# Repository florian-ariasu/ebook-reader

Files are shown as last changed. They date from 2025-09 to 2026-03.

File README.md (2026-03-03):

# OpenBook E-Reader

A portable, open-source e-book reader built around the **ESP32-C6** microcontroller, featuring an energy-efficient E-Paper display, microSD storage, environmental sensing, and a comprehensive power management system.

---

## System Architecture

### Block Diagram

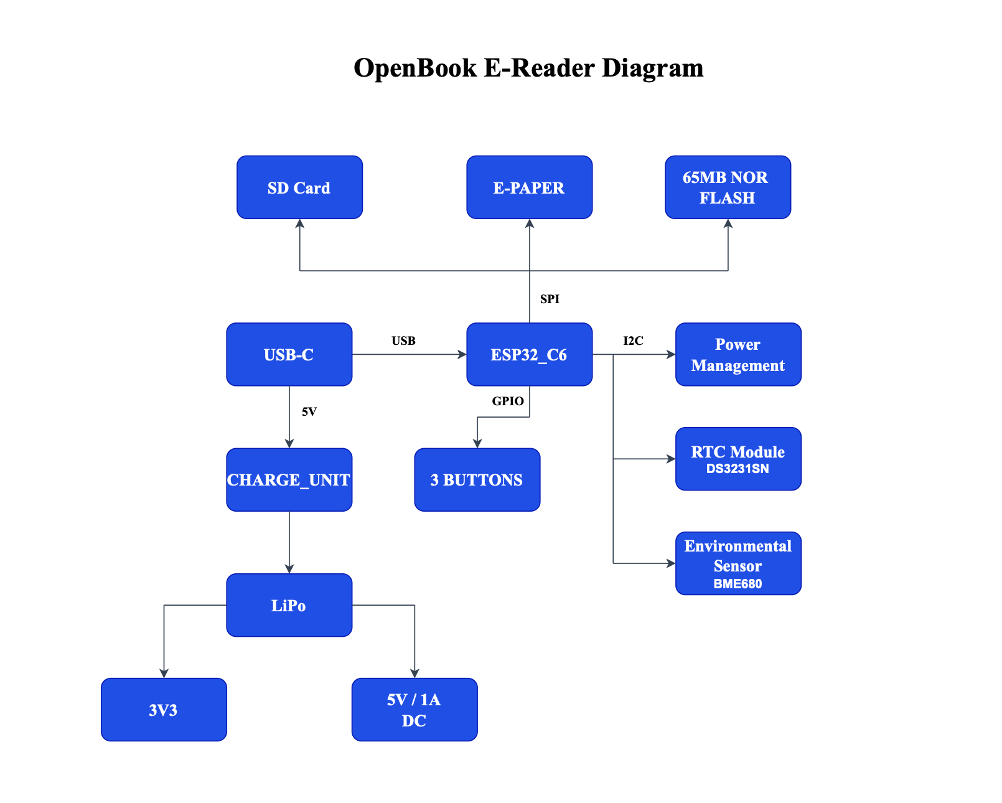
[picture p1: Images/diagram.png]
Block Diagram


The architecture focuses on a high-efficiency 3.3V power rail and shared communication buses (SPI/I2C):

- **ESP32-C6** – Main MCU managing UI, file systems, and wireless connectivity.
- **E-Paper Display** – 1.5" (200x200px) ultra-low-power screen.
- **Power Management** – Includes the **XC6220** 1A LDO for 3.3V regulation and **MCP73831** for Li-Po charging.
- **Battery Monitoring** – **MAX17048G+T10** fuel gauge for precision voltage and SoC tracking.
- **RTC (DS3231SN)** – Real-time clock with a **CPH3225A Supercapacitor** for power backup.
- **BME680 Sensor** – Integrated environmental sensing (Temp, Humidity, Pressure, Gas).
- **External Flash (64MB)** – Winbond **W25Q512** for extended storage and caching.

---

## Bill of Materials (BOM)

Access the full list of components used in this design, including technical specifications and sourcing links:

[Access the Bill of Materials (CSV)](Manufacturing/BOM.csv)

---

## Hardware Overview

### Power Supply & Charging

The system supports primary power via **USB-C** (5V). Charging is handled by the **MCP73831** controller. A high-performance **XC6220A331MR-G** LDO regulator converts the input/battery voltage to a stable **3.3V** to power the ESP32 and peripherals. Circuit protection includes a **USBLC6-2SC6Y** ESD protector and several **PGB1010** varistors.

### Storage Subsystems

- **MicroSD Card (J4)**: SPI-based interface for external library storage
- **NOR Flash (U1)**: 512Mb (64MB) SPI flash memory for firmware extensions

---

## ESP32-C6 Pin Allocation

| Function | ESP32-C6 Pins | Notes |
|---|---|---|
| MicroSD Card | IO2, IO3, IO4, IO5 | SPI |
| E-Paper Display | IO8, IO9, IO10 | SPI |
| Shared I2C Bus | IO6 (SCL), IO7 (SDA) | BME680, RTC, and Fuel Gauge |
| External Flash | IO0, IO1, IO2 | SPI (Shared Bus) |
| Reset Button | IO9 | Reset functionality |
| UI Button (Change) | IO10 | Navigation/Mode control |
| UART Debug | IO20 (TX), IO21 (RX) | Serial communication |

---

## Visual Assets

All design-related documentation is located in the `Images/` directory:

- [Schematic](Images/schematic.png)
- [PCB Top View](Images/pcb-top.png)
- [PCB Bottom View](Images/pcb-bottom.png)
- [3D Model](Images/3d-model-2.png)
- [OpenBook Enclosure](Images/3d-model-enclosure.png)

---

## Known Issues

- **SMD Hole Errors**: Two minor SMD hole warnings were manually approved during the PCB routing phase. These were verified as non-critical for the final manufacturing.

---

## Compliance & Design Constraints

- All SMD components are **0402** package size (unless specified).
- Optimized for single-side component placement (Top-layer).
- Implemented via stitching and dual-layer ground planes for thermal/EMC stability.
- RF Isolation: The ESP32 antenna area is kept clear of copper and traces.
- Passed all Design Rule Checks (DRC) and Electrical Rule Checks (ERC).

---

- Designed the full ESP32-C6 pinout across SPI and I²C buses, integrating the E-Paper display, BME680 sensor, RTC, fuel gauge, NOR flash, and microSD card on shared communication lines.
- Managed the PCB routing phase in Autodesk Fusion 360, resolving DRC and ERC violations and manually approving non-critical SMD hole warnings after physical verification.
- Implemented dual-layer ground planes with via stitching for thermal and EMC stability, and maintained RF isolation by keeping the ESP32 antenna area clear of copper and traces.

---

## Development Notes

This is a 3rd-year TSC course assignment, designed in Autodesk Fusion 360 using a student license.

---

## Licensing

This project is licensed under the **[GPL-3.0 license](LICENCE)**.

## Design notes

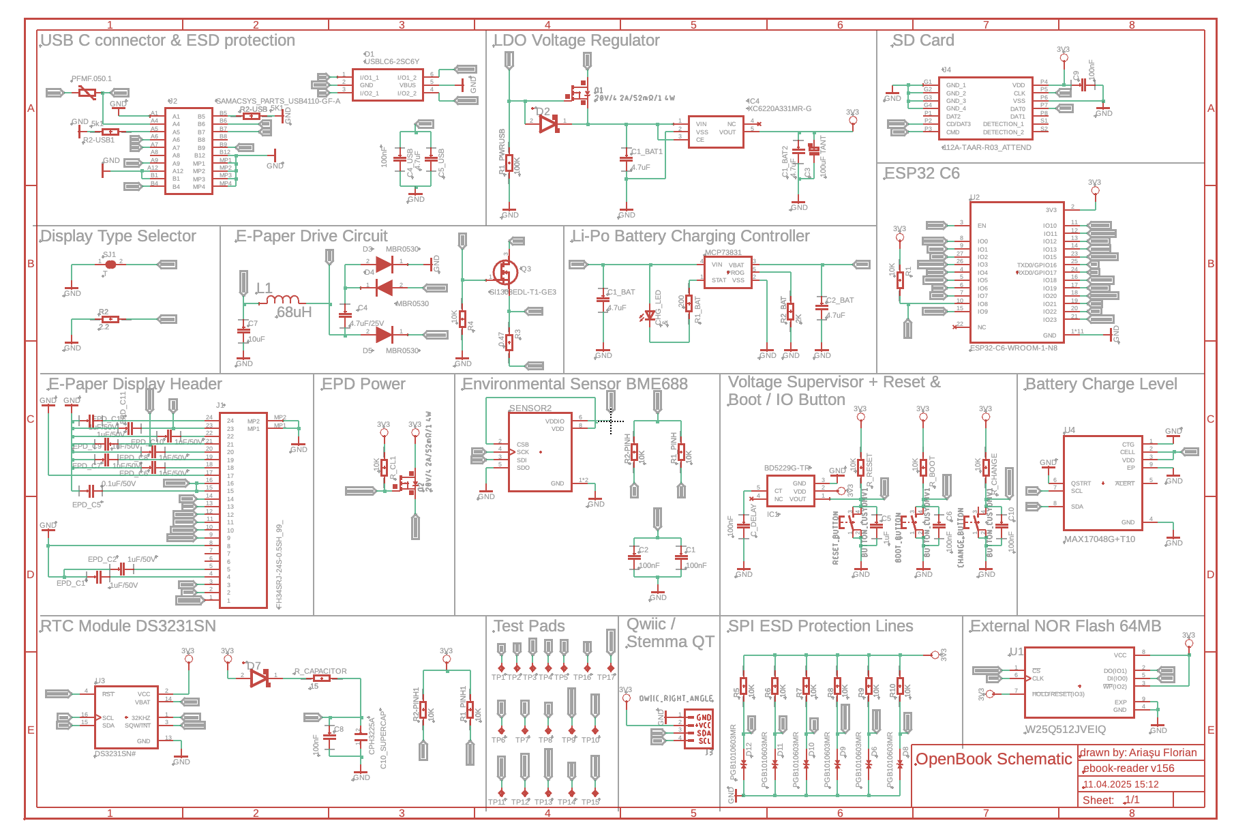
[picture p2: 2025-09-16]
Images/schematic.png

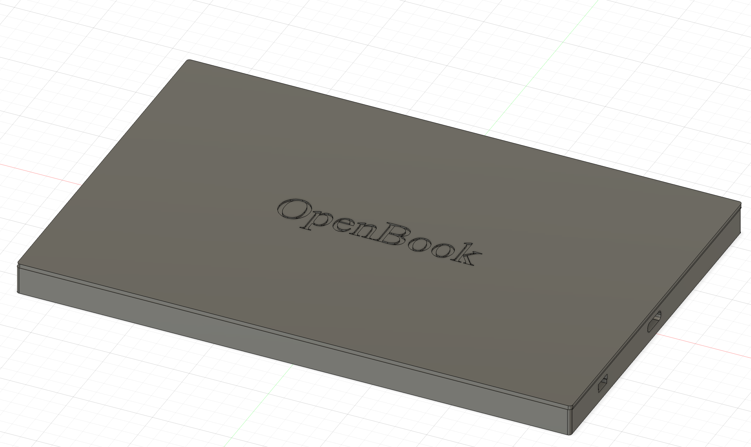
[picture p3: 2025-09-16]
Images/3d-model-enclosure.png

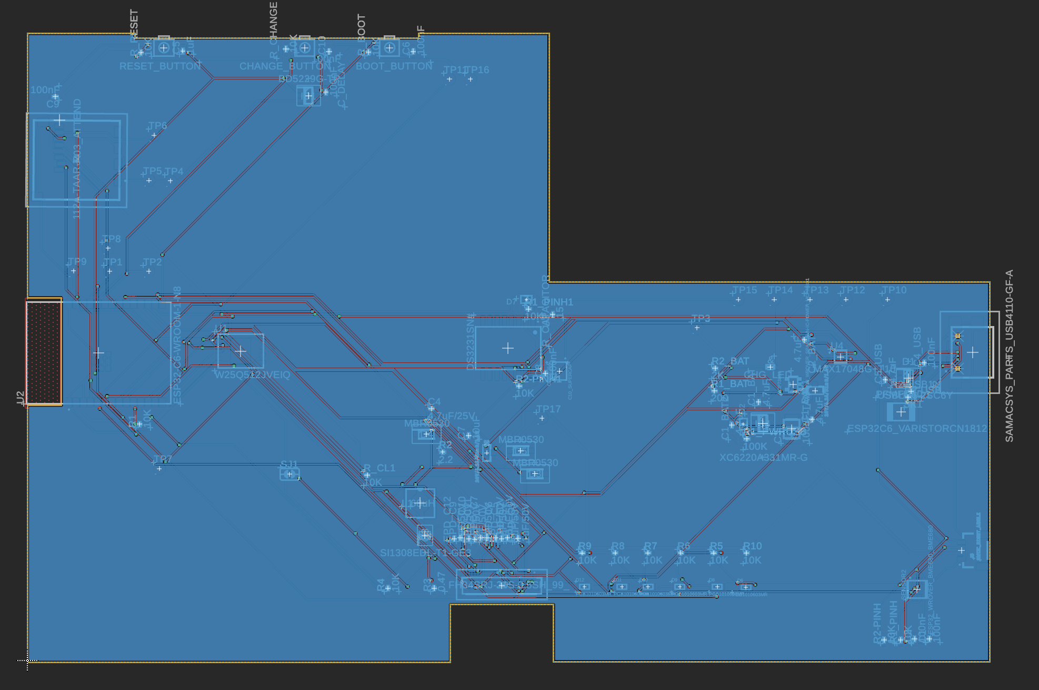
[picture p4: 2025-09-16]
Images/pcb-bottom.png

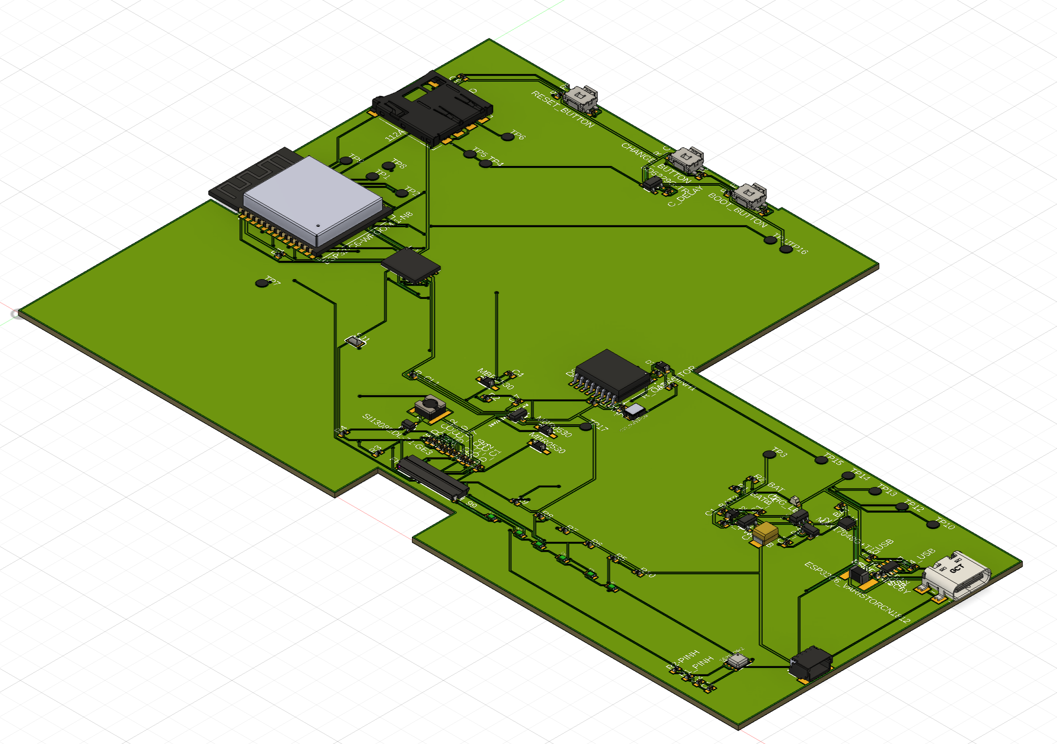
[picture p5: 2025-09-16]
Images/3d-model-2.png

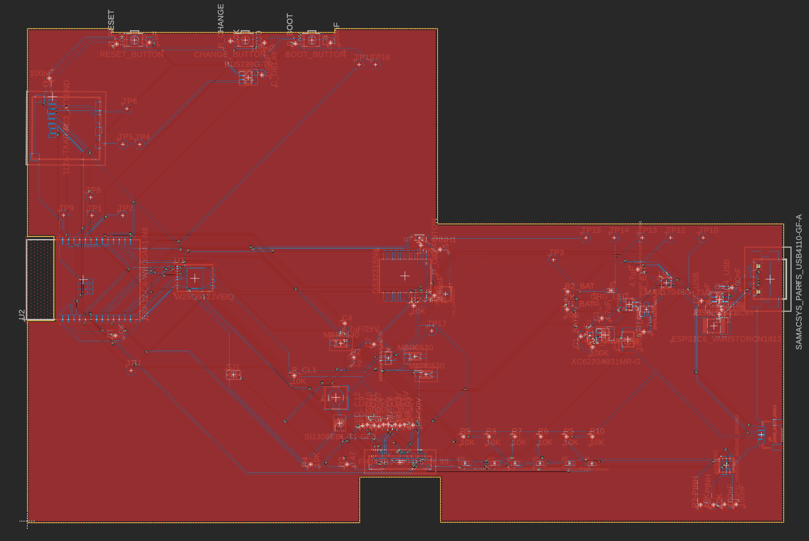
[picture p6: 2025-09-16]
Images/pcb-top.png

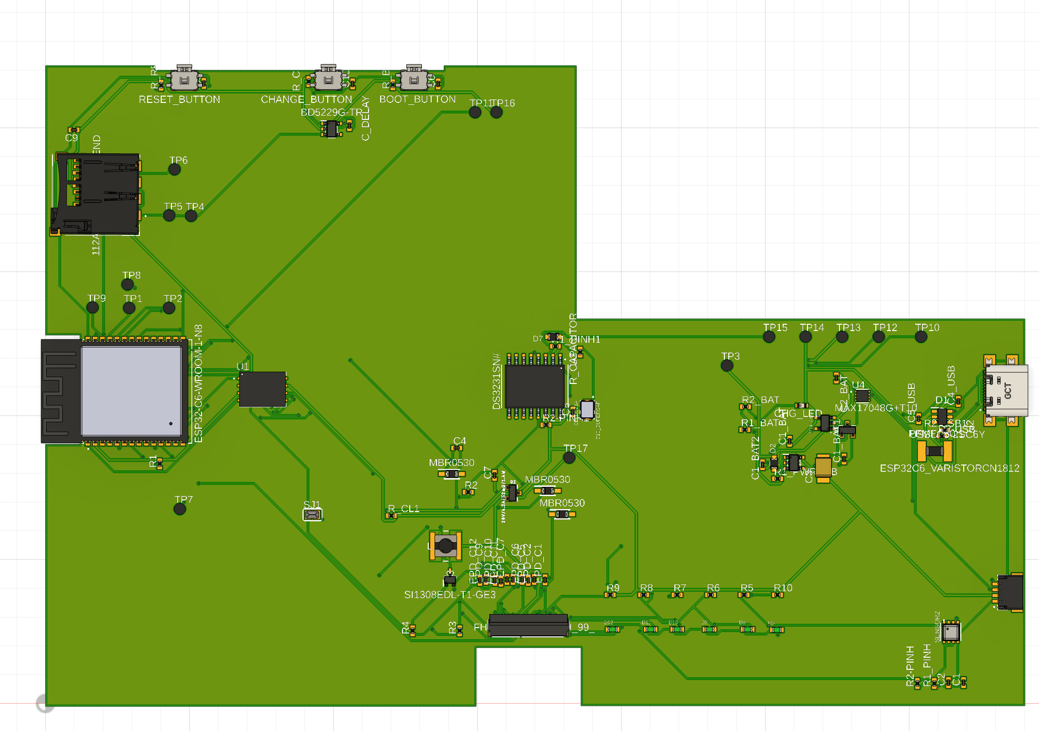
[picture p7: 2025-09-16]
Images/3d-model-1.png

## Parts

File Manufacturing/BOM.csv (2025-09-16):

Qty | Value | Device | Package | Parts | Description | ARROW_PART_NUMBER | ARROW_PRICE-STOCK | AVAILABILITY | CENTROID_NOT_SPECIFIED | CHECK_PRICES | COPYRIGHT | DATASHEET | DESCRIPTION | DIGIKEY_DESCRIPTION | DIGIKEY_PART_NUMBER | HEIGHT | LEAD_FREE | MANUFACTURER_NAME | MANUFACTURER_PART_NUMBER | MF | MFR_NAME | MOUSER_PART_NUMBER | MOUSER_PRICE-STOCK | MOUSER_TESTING_PART_NUMBER | MOUSER_TESTING_PRICE-STOCK | MP | MPN | PACKAGE | POPULARITY | PREFIX | PRICE | PROD_ID | PURCHASE-URL | ROHS | SNAPEDA_LINK | SPICEMODEL | SPICEPREFIX | TEMPERATURE_RANGE_HIGH | TEMPERATURE_RANGE_LOW | TP_SIGNAL_NAME | VALUE
1 |  | ADAFRUIT_LEDCHIP-LED0603 | ADAFRUIT_CHIP-LED0603 | CHG_LED | LED
6 |  | ESP32_WROVER_EAGLE-LTSPICE_RR0402 | ESP32_WROVER_EAGLE-LTSPICE_R0402 | R5, R6, R7, R8, R9, R10 | RESISTOR, European symbol |  |  |  |  |  |  |  |  |  |  |  |  |  |  |  |  |  |  |  |  |  |  |  |  |  |  |  |  |  |  | NONE | R
1 |  | SJ | SJ | SJ1 | SMD solder JUMPER |  |  |  |  |  |  |  |  |  |  |  |  |  |  |  |  |  |  |  |  |  |  |  | 3
1 | 0.1uF/50V | EAGLE-LTSPICE_CC0402 | EAGLE-LTSPICE_C0402 | EPD_C5 | CAPACITOR, European symbol |  |  |  |  |  |  |  |  |  |  |  |  |  |  |  |  |  |  |  |  |  |  |  |  |  |  |  |  |  |  | NONE | C
1 | 0.47 | ESP32_WROVER_EAGLE-LTSPICE_RR0402 | ESP32_WROVER_EAGLE-LTSPICE_R0402 | R3 | RESISTOR, European symbol |  |  |  |  |  |  |  |  |  |  |  |  |  |  |  |  |  |  |  |  |  |  |  |  |  |  |  |  |  |  | NONE | R
1 | 100K | ESP32_WROVER_EAGLE-LTSPICE_RR0402 | ESP32_WROVER_EAGLE-LTSPICE_R0402 | R1_PWRUSB | RESISTOR, European symbol |  |  |  |  |  |  |  |  |  |  |  |  |  |  |  |  |  |  |  |  |  |  |  |  |  |  |  |  |  |  | NONE | R
8 | 100nF | EAGLE-LTSPICE_CC0402 | EAGLE-LTSPICE_C0402 | C1, C2, C4_USB, C6, C8, C9, C10, C_DELAY | CAPACITOR, European symbol |  |  |  |  |  |  |  |  |  |  |  |  |  |  |  |  |  |  |  |  |  |  |  |  |  |  |  |  |  |  | NONE | C
1 | 100uF | RCL_CPOL-EUCT3528 | RCL_CT3528 | C3 | POLARIZED CAPACITOR, European symbol |  |  |  |  |  |  |  |  |  |  |  |  |  |  |  |  |  |  |  |  |  |  |  | 0 |  |  |  |  |  |  |  | C
10 | 10K | ESP32_WROVER_EAGLE-LTSPICE_RR0402 | ESP32_WROVER_EAGLE-LTSPICE_R0402 | R1, R1_PINH, R1_PINH1, R2-PINH, R2-PINH1, R4, R_BOOT, R_CHANGE, R_CL1, R_RESET | RESISTOR, European symbol |  |  |  |  |  |  |  |  |  |  |  |  |  |  |  |  |  |  |  |  |  |  |  |  |  |  |  |  |  |  | NONE | R
1 | 10uF | EAGLE-LTSPICE_CC0402 | EAGLE-LTSPICE_C0402 | C7 | CAPACITOR, European symbol |  |  |  |  |  |  |  |  |  |  |  |  |  |  |  |  |  |  |  |  |  |  |  |  |  |  |  |  |  |  | NONE | C
1 | 112A-TAAR-R03_ATTEND | 112A-TAAR-R03_ATTEND | 112ATAARR03ATTEND | J4 | Micro SD Card Socket, Push-Push Type, Top Mount, SMT, H=1.83mm, 10u |  |  |  |  |  |  |  | Micro SD Card Socket | Push-Push Type | Top Mount | SMT | H=1.83mm | 10u |  |  | 1.9mm |  | ATTEND | 112A-TAAR-R03 ATTEND
1 | 15 | ESP32_WROVER_EAGLE-LTSPICE_RR0402 | ESP32_WROVER_EAGLE-LTSPICE_R0402 | R_CAPACITOR | RESISTOR, European symbol |  |  |  |  |  |  |  |  |  |  |  |  |  |  |  |  |  |  |  |  |  |  |  |  |  |  |  |  |  |  | NONE | R
1 | 1uF | EAGLE-LTSPICE_CC0402 | EAGLE-LTSPICE_C0402 | C5 | CAPACITOR, European symbol |  |  |  |  |  |  |  |  |  |  |  |  |  |  |  |  |  |  |  |  |  |  |  |  |  |  |  |  |  |  | NONE | C
9 | 1uF/50V | EAGLE-LTSPICE_CC0402 | EAGLE-LTSPICE_C0402 | EPD_C1, EPD_C2, EPD_C6, EPD_C7, EPD_C8, EPD_C9, EPD_C10, EPD_C11, EPD_C12 | CAPACITOR, European symbol |  |  |  |  |  |  |  |  |  |  |  |  |  |  |  |  |  |  |  |  |  |  |  |  |  |  |  |  |  |  | NONE | C
1 | 2.2 | ESP32_WROVER_EAGLE-LTSPICE_RR0402 | ESP32_WROVER_EAGLE-LTSPICE_R0402 | R2 | RESISTOR, European symbol |  |  |  |  |  |  |  |  |  |  |  |  |  |  |  |  |  |  |  |  |  |  |  |  |  |  |  |  |  |  | NONE | R
1 | 200 | ESP32_WROVER_EAGLE-LTSPICE_RR0402 | ESP32_WROVER_EAGLE-LTSPICE_R0402 | R1_BAT | RESISTOR, European symbol |  |  |  |  |  |  |  |  |  |  |  |  |  |  |  |  |  |  |  |  |  |  |  |  |  |  |  |  |  |  | NONE | R
2 | 20V/4.2A/52mΩ/1.4W | ESP32_WROVER_SPARKFUN-DISCRETESEMI_MOSFET_PCH-DMG2305UX-7 | ESP32_WROVER_SPARKFUN-DISCRETESEMI_SOT23-3 | Q1, Q2 | P-channel MOSFETs |  |  |  |  |  |  |  |  |  |  |  |  |  |  |  |  |  |  |  |  |  |  |  |  |  |  | TRAN-14388 |  |  |  |  |  |  |  |  | 20V/4.2A/52mΩ/1.4W
1 | 2K | ESP32_WROVER_EAGLE-LTSPICE_RR0402 | ESP32_WROVER_EAGLE-LTSPICE_R0402 | R2_BAT | RESISTOR, European symbol |  |  |  |  |  |  |  |  |  |  |  |  |  |  |  |  |  |  |  |  |  |  |  |  |  |  |  |  |  |  | NONE | R
5 | 4.7uF | EAGLE-LTSPICE_CC0402 | EAGLE-LTSPICE_C0402 | C1_BAT, C1_BAT1, C1_BAT2, C2_BAT, C5_USB | CAPACITOR, European symbol |  |  |  |  |  |  |  |  |  |  |  |  |  |  |  |  |  |  |  |  |  |  |  |  |  |  |  |  |  |  | NONE | C
1 | 4.7uF/25V | EAGLE-LTSPICE_CC0402 | EAGLE-LTSPICE_C0402 | C4 | CAPACITOR, European symbol |  |  |  |  |  |  |  |  |  |  |  |  |  |  |  |  |  |  |  |  |  |  |  |  |  |  |  |  |  |  | NONE | C
1 | 5K1 | ESP32_WROVER_EAGLE-LTSPICE_RR0402 | ESP32_WROVER_EAGLE-LTSPICE_R0402 | R2-USB | RESISTOR, European symbol |  |  |  |  |  |  |  |  |  |  |  |  |  |  |  |  |  |  |  |  |  |  |  |  |  |  |  |  |  |  | NONE | R
1 | 5k1 | ESP32_WROVER_EAGLE-LTSPICE_RR0402 | ESP32_WROVER_EAGLE-LTSPICE_R0402 | R2-USB1 | RESISTOR, European symbol |  |  |  |  |  |  |  |  |  |  |  |  |  |  |  |  |  |  |  |  |  |  |  |  |  |  |  |  |  |  | NONE | R
1 | 68uH | 744043680IND_4828-WE-TPC_WRE | IND_4828-WE-TPC_WRE | L1 |  |  |  |  |  |  | Copyright (C) 2024 Ultra Librarian. All rights reserved. |  |  |  |  |  |  |  | 744043680 |  | Wurth Electronics
1 | BD5229G-TR | BD5229G-TR | SOT95P280X125-5N | IC1 | Voltage Detector with Adjustable Delay Time: CMOS processes are utilized to develop high precision, low current consumption CMOS reset ICs that allow arbitrary setting of the delay time. The extensive lineup includes both Nch Open Drain and CMOS output types in a wide range of detection voltages (from 2.3V to 6.0V, in 0.1V steps), enabling selection of the ideal solution based on customer requirements. In addition, the entire series is of course both lead-free and RoHS-compliant. |  |  |  |  |  |  |  | Voltage Detector with Adjustable Delay Time: CMOS processes are utilized to develop high precision | low current consumption CMOS reset ICs that allow arbitrary setting of the delay time. The extensive lineup includes both Nch Open Drain and CMOS output types in a wide range of detection voltages (from 2.3V to 6.0V | in 0.1V steps) | enabling selection of the ideal solution based on customer requirements. In addition | the entire series is of course both lead-free and RoHS-compliant. |  |  | 1.25mm |  | ROHM Semiconductor | BD5229G-TR |  |  | 755-BD5229G-TR | https://www.mouser.co.uk/ProductDetail/ROHM-Semiconductor/BD5229G-TR?qs=4kLU8WoGk0vvnhrrYwdszw%3D%3D
3 | BUTTON_CUSYOMV1 | BUTTON_CUSYOMV1 | MYBUTTON | BOOT_BUTTON, CHANGE_BUTTON, RESET_BUTTON
1 | CPH3225A | CPH3225A | CAPCP3225X100N | C10_SUPERCAP | Cap 0.011F 3.3V 1210 Flat Check availability |  |  | Not in stock |  | https://www.snapeda.com/parts/CPH3225A/Seiko+Instruments/view-part/?ref=eda |  |  | 11 mF (EDLC) Supercapacitor 3.3 V 1210 (3225 Metric) - - |  |  |  |  |  |  | Seiko Instruments |  |  |  |  |  | CPH3225A |  | 1210 Seiko |  |  | None |  | https://www.snapeda.com/api/url_track_click_mouser/?unipart_id=562593&manufacturer=Seiko Instruments&part_name=CPH3225A&search_term=None |  | https://www.snapeda.com/parts/CPH3225A/Seiko+Instruments/view-part/?ref=snap
1 | DS3231SN# | DS3231SN# | SOIC127P1032X265-16N | U3 | Real Time Clock Serial 16-Pin SOIC W T/R Check availability |  |  | In Stock |  | https://www.snapeda.com/parts/DS3231SN%23/Analog+Devices/view-part/?ref=eda |  |  | Extremely Accurate I²C-Integrated RTC/TCXO/Crystal |  |  |  |  |  |  | Analog Devices |  |  |  |  |  | DS3231SN# |  | SOIC-16 Maxim |  |  | None |  | https://www.snapeda.com/api/url_track_click_mouser/?unipart_id=99048&manufacturer=Analog Devices&part_name=DS3231SN#&search_term=None |  | https://www.snapeda.com/parts/DS3231SN%23/Analog+Devices/view-part/?ref=snap
1 | ESP32-C6-WROOM-1-N8 | ESP32-C6-WROOM-1-N8 | XCVR_ESP32-C6-WROOM-1-N8 | U2 | Check availability |  |  | In Stock |  | https://www.snapeda.com/parts/ESP32-C6-WROOM-1-N8/Espressif+Systems/view-part/?ref=eda |  |  | Multiprotocol Modules ESP32-C6 module | Wi-Fi 6 in 2.4 GHz band | Bluetooth 5 | Zigbee 3.0 and Thread. ESP34-WROOM Compatible - ENGINEERING SAMPLE |  |  |  |  |  |  | Espressif Systems |  |  |  |  |  | ESP32-C6-WROOM-1-N8 |  | None |  |  | None |  |  |  | https://www.snapeda.com/parts/ESP32-C6-WROOM-1-N8/Espressif+Systems/view-part/?ref=snap
1 | ESP32C6_VARISTORCN1812 | ESP32C6_VARISTORCN1812 | ESP32C6_VARISTOR_CT/CN1812 | PFMF.050.1 | VARISTOR |  |  |  |  |  |  |  |  |  |  |  |  |  |  |  |  |  |  |  |  |  |  |  | 0
2 | ESP32_WROVER_AVX---SD0805S020S1R0_AVX_SD0805S020S1R0_0_0AVX_SD0805S020S1R0_0_0 | ESP32_WROVER_AVX---SD0805S020S1R0_AVX_SD0805S020S1R0_0_0AVX_SD0805S020S1R0_0_0 | ESP32_WROVER_AVX---SD0805S020S1R0_AVX_SD0805S020S1R0_0 | D2, D7 | Schottky Barrier Rectifier Diode |  |  |  | No |  |  | http://datasheets.avx.com/schottky.pdf |  | DIODE SCHOTTKY 20V 1A 0805 | 478-7800-1-ND |  | yes |  |  | AVX |  | 581-SD0805S020S1R0 |  |  |  |  |  | 0805 (2012 metric) |  | D |  |  |  | yes |  |  |  | +125°C | -55°C
1 | ESP32_WROVER_BME680_BME680 | ESP32_WROVER_BME680_BME680 | ESP32_WROVER_BME680_PSON80P300X300X100-8N | SENSOR2 | Integrated Environmental Unit |  |  | Unavailable |  |  |  |  | Integrated Environmental Unit |  |  |  |  |  |  | Bosch Sensortec |  |  |  |  |  | BME680 |  | LGA-8 Bosch Tools |  |  | None
1 | ESP32_WROVER_SPARKFUN-IC-POWER_MCP73831 | ESP32_WROVER_SPARKFUN-IC-POWER_MCP73831 | ESP32_WROVER_SPARKFUN-IC-POWER_SOT23-5 | MCP73831 | MCP73831T Li-Ion, Li-Pol Controller |  |  |  |  |  |  |  |  |  |  |  |  |  |  |  |  |  |  |  |  |  |  |  |  |  |  | IC-09995
1 | FH34SRJ-24S-0.5SH_99_ | FH34SRJ-24S-0.5SH_99_ | FH34SRJ24S05SH99 | J1 | (0.50mm) Surface Mount, Right Angle |  |  |  |  |  |  |  | 24 Position FFC | FPC Connector Contacts | (0.50mm) Surface Mount | Right Angle |  |  | 1.1mm |  | Hirose | FH34SRJ-24S-0.5SH(99) |  |  | 798-FH34SRJ24S05SH99 | https://www.mouser.co.uk/ProductDetail/Hirose-Connector/FH34SRJ-24S-0.5SH99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
1 | MAX17048G+T10 | MAX17048G+T10 | SON50P200X200X80-9N | U4 | Check availability |  |  | In Stock |  | https://www.snapeda.com/parts/MAX17048G+T10/Analog+Devices/view-part/?ref=eda |  |  | 3µA 1-Cell/2-Cell Fuel Gauge with ModelGauge |  |  |  |  |  |  | Analog Devices |  |  |  |  |  | MAX17048G+T10 |  | TDFN-8 Maxim |  |  | None |  | https://www.snapeda.com/api/url_track_click_mouser/?unipart_id=329239&manufacturer=Analog Devices&part_name=MAX17048G+T10&search_term=None |  | https://www.snapeda.com/parts/MAX17048G+T10/Analog+Devices/view-part/?ref=snap
3 | MBR0530 | MBR0530 | SOD3716X135N | D3, D4, D5 | ON SEMICONDUCTOR - MBR0530 - DIODE, SCHOTTKY, 0.5A, 30V, SOD-123 |  |  | In Stock |  | https://www.snapeda.com/parts/MBR0530/Onsemi/view-part/?ref=eda |  |  | Diode Schottky 30 V 500mA Surface Mount SOD-123 |  |  |  |  |  |  | ON Semiconductor |  |  |  |  |  | MBR0530 |  | SOD-123-2 ON Semiconductor |  |  | None |  | https://www.snapeda.com/api/url_track_click_mouser/?unipart_id=179458&manufacturer=ON Semiconductor&part_name=MBR0530&search_term=None |  | https://www.snapeda.com/parts/MBR0530/Onsemi/view-part/?ref=snap
6 | PGB1010603MR | PGB1010603MR | DIOC1608X36N | D6, D8, D9, D10, D11, D12 | Check availability |  |  | In Stock |  | https://www.snapeda.com/parts/PGB1010603MR/Littelfuse/view-part/?ref=eda |  |  | 150V (Typ) Clamp - Ipp Tvs Diode Surface Mount 0603 (1608 Metric) |  |  |  |  |  |  | Littelfuse Inc. |  |  |  |  |  | PGB1010603MR |  | 0603 Littelfuse Inc. |  |  | None |  | https://www.snapeda.com/api/url_track_click_mouser/?unipart_id=5659453&manufacturer=Littelfuse Inc.&part_name=PGB1010603MR&search_term=None |  | https://www.snapeda.com/parts/PGB1010603MR/Littelfuse/view-part/?ref=snap
1 | QWIIC_RIGHT_ANGLE | QWIIC_CONNECTORJS-1MM | JST04_1MM_RA | J3 | SparkFun I2C Standard Qwiic Connector |  |  |  |  |  |  |  |  |  |  |  |  |  |  |  |  |  |  |  |  |  |  |  |  |  |  | CONN-13694 |  |  |  |  |  |  |  |  | QWIIC_RIGHT_ANGLE
1 | SAMACSYS_PARTS_USB4110-GF-A | SAMACSYS_PARTS_USB4110-GF-A | SAMACSYS_PARTS_USB4110GFA | J2 | CONN USB 2.0 TYPE-C R/A SMT |  |  |  |  |  |  |  | CONN USB 2.0 TYPE-C R/A SMT |  |  | 3.26mm |  | GCT (GLOBAL CONNECTOR TECHNOLOGY) | USB4110-GF-A |  |  | 640-USB4110-GF-A | https://www.mouser.co.uk/ProductDetail/GCT/USB4110-GF-A?qs=KUoIvG%2F9IlYiZvIXQjyJeA%3D%3D
1 | SI1308EDL-T1-GE3 | SI1308EDL-T1-GE3 | SOT65P210X110-3N | Q3 | MOSFET N-Ch 30V 1.5A TrenchFET SC70 Vishay Si1308EDL-T1-GE3 N-channel MOSFET Transistor, 1.5 A, 30 V, 3-Pin SC-70 |  |  | In Stock |  | https://www.snapeda.com/parts/SI1308EDL-T1-GE3/Vishay+Siliconix/view-part/?ref=eda |  |  | Si1308EDL-T1-GE3 N-channel MOSFET Transistor | 1.5 A | 30 V | 3-Pin SC-70 | Siliconix / Vishay SI1308EDL-T1-GE3 |  |  |  |  |  |  | Vishay Siliconix |  |  |  |  |  | SI1308EDL-T1-GE3 |  | SOT-323 Vishay Semiconductor |  |  | None |  | https://www.snapeda.com/api/url_track_click_mouser/?unipart_id=274603&manufacturer=Vishay Siliconix&part_name=SI1308EDL-T1-GE3&search_term=None |  | https://www.snapeda.com/parts/SI1308EDL-T1-GE3/Vishay+Siliconix/view-part/?ref=snap
17 | TPTP20R | TPTP20R | TP20R | TP1, TP2, TP3, TP4, TP5, TP6, TP7, TP8, TP9, TP10, TP11, TP12, TP13, TP14, TP15, TP16, TP17 | Test pad |  |  |  |  |  |  |  |  |  |  |  |  |  |  |  |  |  |  |  |  |  |  |  | 2
1 | USBLC6-2SC6Y | USBLC6-2SC6Y | SOT95P280X145-6N | D1 | Low Cap. ESD Protection Auto SOT-23-6 STMicroelectronics USBLC6-2SC6Y, Dual Uni-Directional TVS Diode Array, 6-Pin SOT-23 |  |  | In Stock |  | https://www.snapeda.com/parts/USBLC6-2SC6Y/STMicroelectronics/view-part/?ref=eda |  |  | 17V Clamp 5A (8/20µs) Ipp Tvs Diode Surface Mount SOT-23-6 |  |  |  |  |  |  | STMicroelectronics |  |  |  |  |  | USBLC6-2SC6Y |  | SOT-23-6 STMicroelectronics |  |  | None |  |  |  | https://www.snapeda.com/parts/USBLC6-2SC6Y/STMicroelectronics/view-part/?ref=snap
1 | W25Q512JVEIQ | W25Q512JVEIQ | SON127P600X800X80-9N | U1 | Check availability |  |  | In Stock |  | https://www.snapeda.com/parts/W25Q512JVEIQ/Winbond+Electronics/view-part/?ref=eda |  |  | FLASH - NOR Memory IC 512Mb (64M x 8) SPI - Quad I/O 133 MHz 8-WSON (8x6) |  |  |  |  |  |  | Winbond Electronics |  |  |  |  |  | W25Q512JVEIQ |  | Package |  |  | None |  |  |  | https://www.snapeda.com/parts/W25Q512JVEIQ/Winbond+Electronics/view-part/?ref=snap
1 | XC6220A331MR-G | XC6220A331MR-G | SOT95P280X120-5N | IC4 | LDO Voltage Regulators |  |  |  |  |  |  |  | LDO Voltage Regulators |  |  | 1.2mm |  | Torex | XC6220A331MR-G |  |  | 865-XC6220A331MR-G | https://www.mouser.co.uk/ProductDetail/Torex-Semiconductor/XC6220A331MR-G?qs=AsjdqWjXhJ8ZSWznL1J0gg%3D%3D

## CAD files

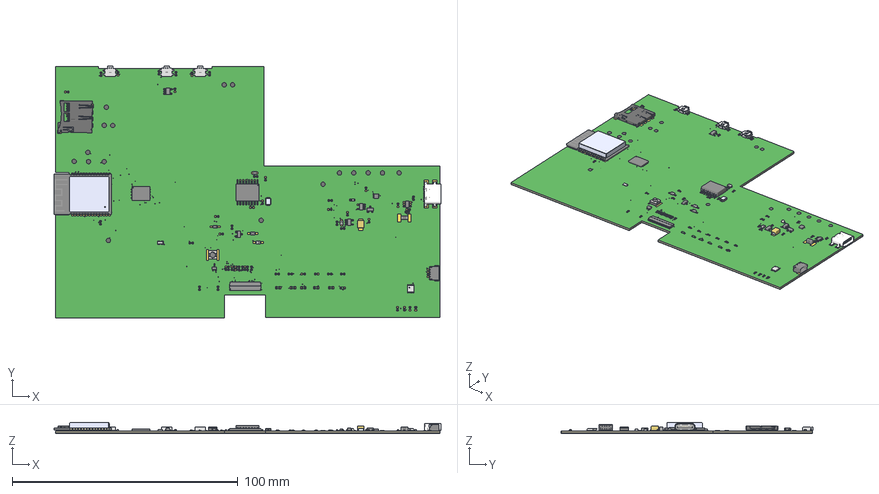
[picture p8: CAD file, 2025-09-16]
Mechanical/ebook-reader v109.3mf
171.4 x 111.5 x 4.71 mm
Board
CopperHoles

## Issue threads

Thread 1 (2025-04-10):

Lipsă decupaj placă

saraflorean, 2025-04-10:
**Descriere:**

Componenta U2 (ESP32-C6-WROOM-1) nu respecta constrângerea menționată in cerință: PCB-ul trebuie tăiat în jurul antenei.

**Imagine exemplu:**
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

Closed 2025-04-10.

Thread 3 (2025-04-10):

Dimensiune fire trasee de putere

saraflorean, 2025-04-10:
**Descriere:**

Există clasă pentru traseele de putere și e definită dimensiunea firului de 0.3 mm, dar nu sunt adăugate traseele de putere (ex. VBUS, 3V3, VBAT etc.)

**Imgaine sucgestivă:**

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

**Recomandare:**

Trebuie doar să selectezi clasa Power deja creată și să adaugi traseele de putere cu drag and drop.
Această modificare e posibil să afecteze rutarea, unele piese cum ar fi bobina necesitând o modificare a pad-urilor, astfel încât firele mai groase să poată fi conectate.

Pentru eventuala problemă sugerată mai sus, trebuie să modifici pad-urile pentru a avea o dimensiune mai mare, apoi să înlocuiești piesa actualizată în PCB.

Closed 2025-04-11.

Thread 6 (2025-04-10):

Lipsă componente 3d/amplasare incorectă

saraflorean, 2025-04-10:
**Descriere:**

Lipsește o componentă 3D: Sensor 2 (vezi prima imagine).

Componenta J3 (Qwiic / Stemma QT) este amplasată prea departe de marginea plăcuței, fiind o componentă ce necesită plug in, se pot întâmpina dificultăți ulterior. De asemenea, componenta nu este poziționată corect pe plăcuță, pinii nefăcând contact (vezi imaginea 2).

Componenta C10_SUPERCAP este poziționată incorect, pinii fiind in aer (vezi imaginea 3) -> trebuie rotită pentru a ajunge pinii în poziția corectă.

**Imagini sugestive:**

(Sensor 2)
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

(J3)
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

(C10_SUPERCAP)
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

Closed 2025-04-11.

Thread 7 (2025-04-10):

Denumiri suprapuse pe board-ul 3D

saraflorean, 2025-04-10:
**Descriere:**

Denumirile componentelor se suprapun pe plăcuță, astfel fiind dificil de identificat.

Acestea pot fi redimensionate pentru a încăpea în dreptul componentelor sau componentele să fie puțin mai distanțate pentru a face spațiu pentru denumire.

**Imagine sugestivă:**

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

Closed 2025-04-11.

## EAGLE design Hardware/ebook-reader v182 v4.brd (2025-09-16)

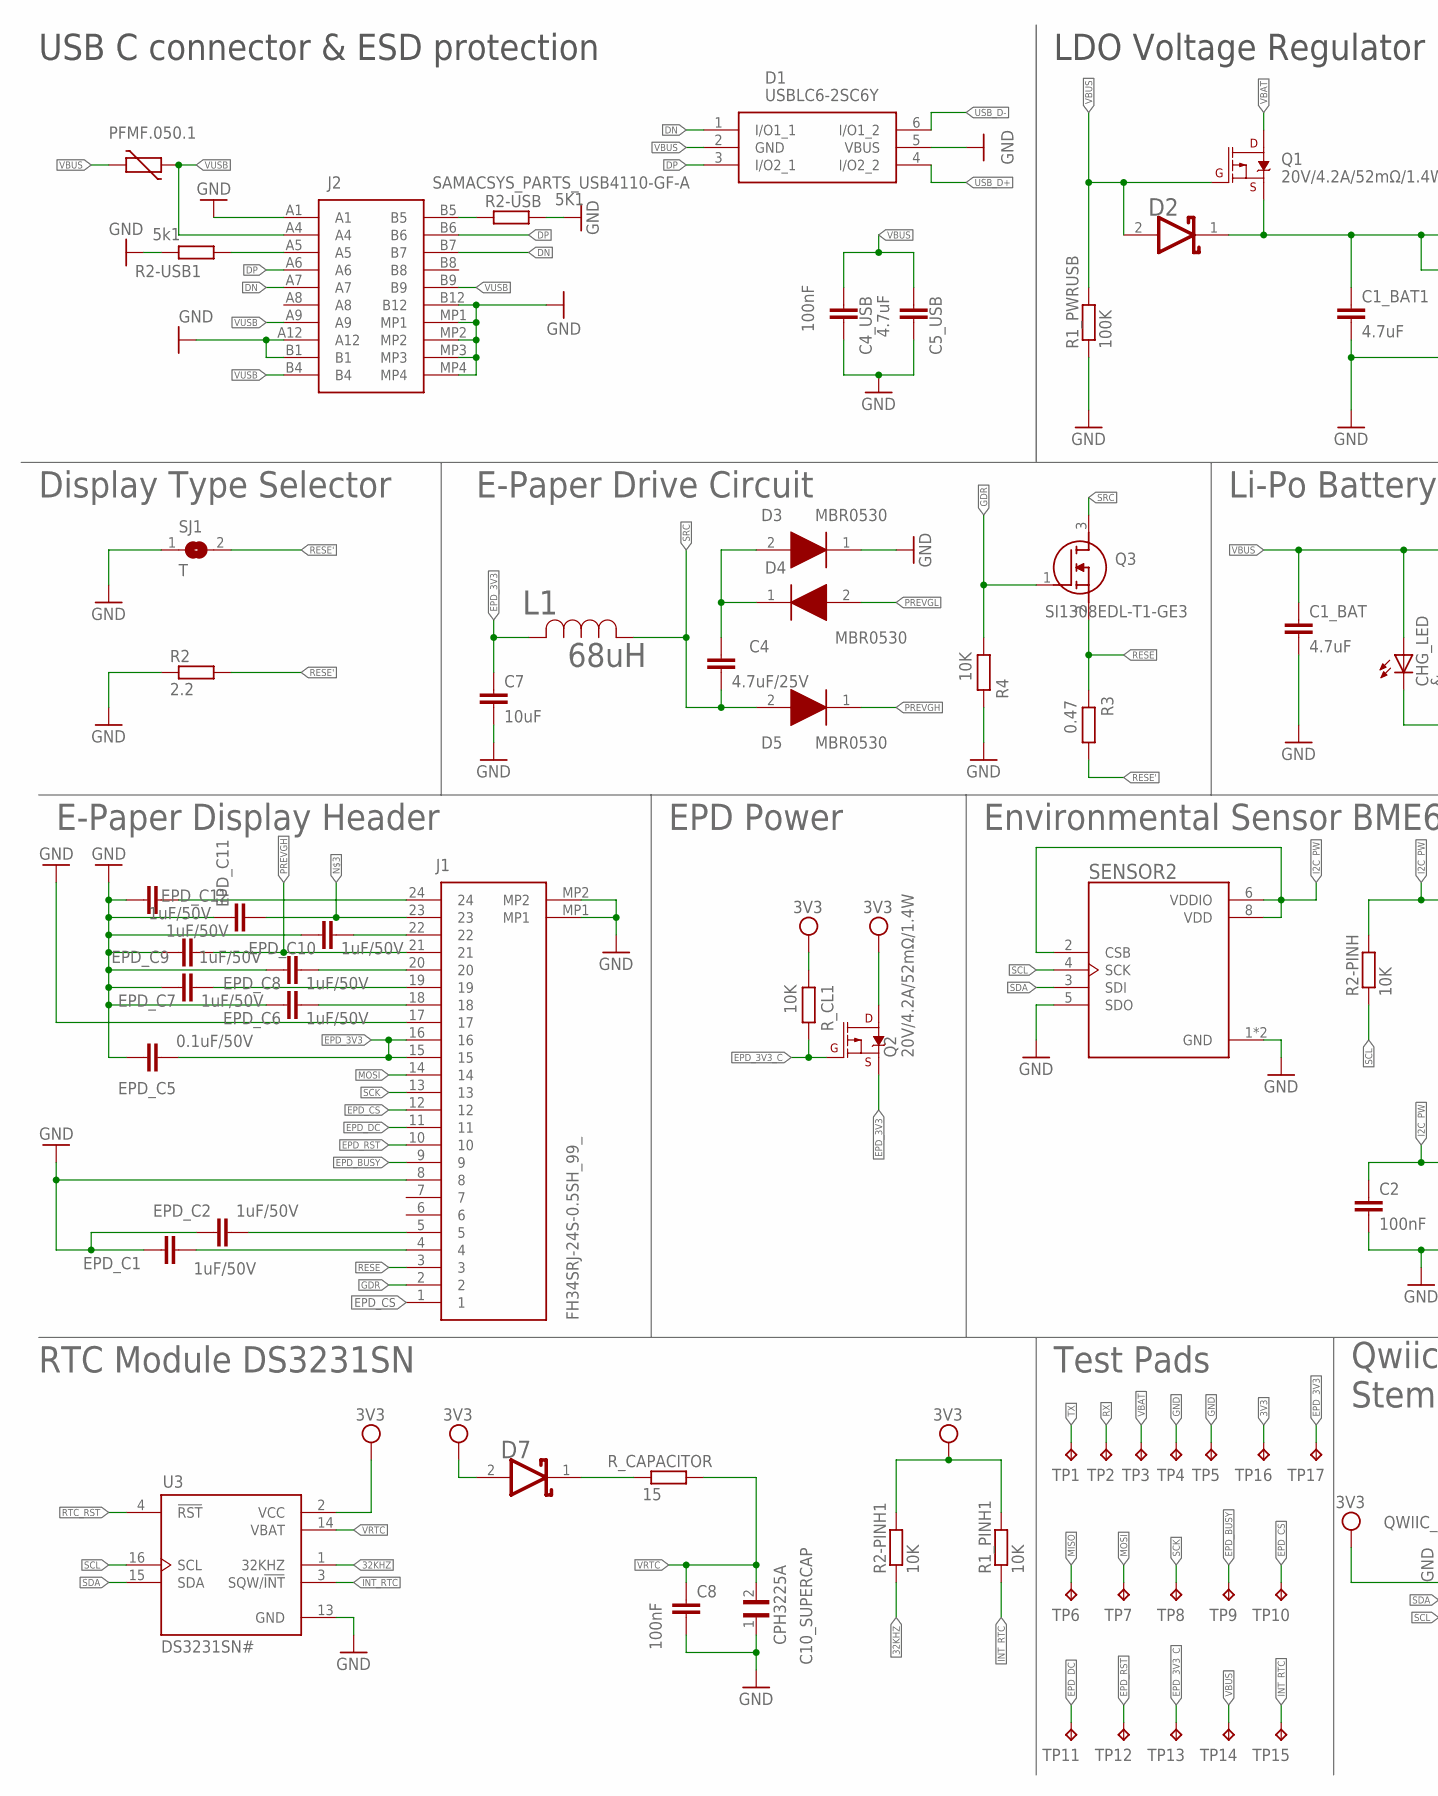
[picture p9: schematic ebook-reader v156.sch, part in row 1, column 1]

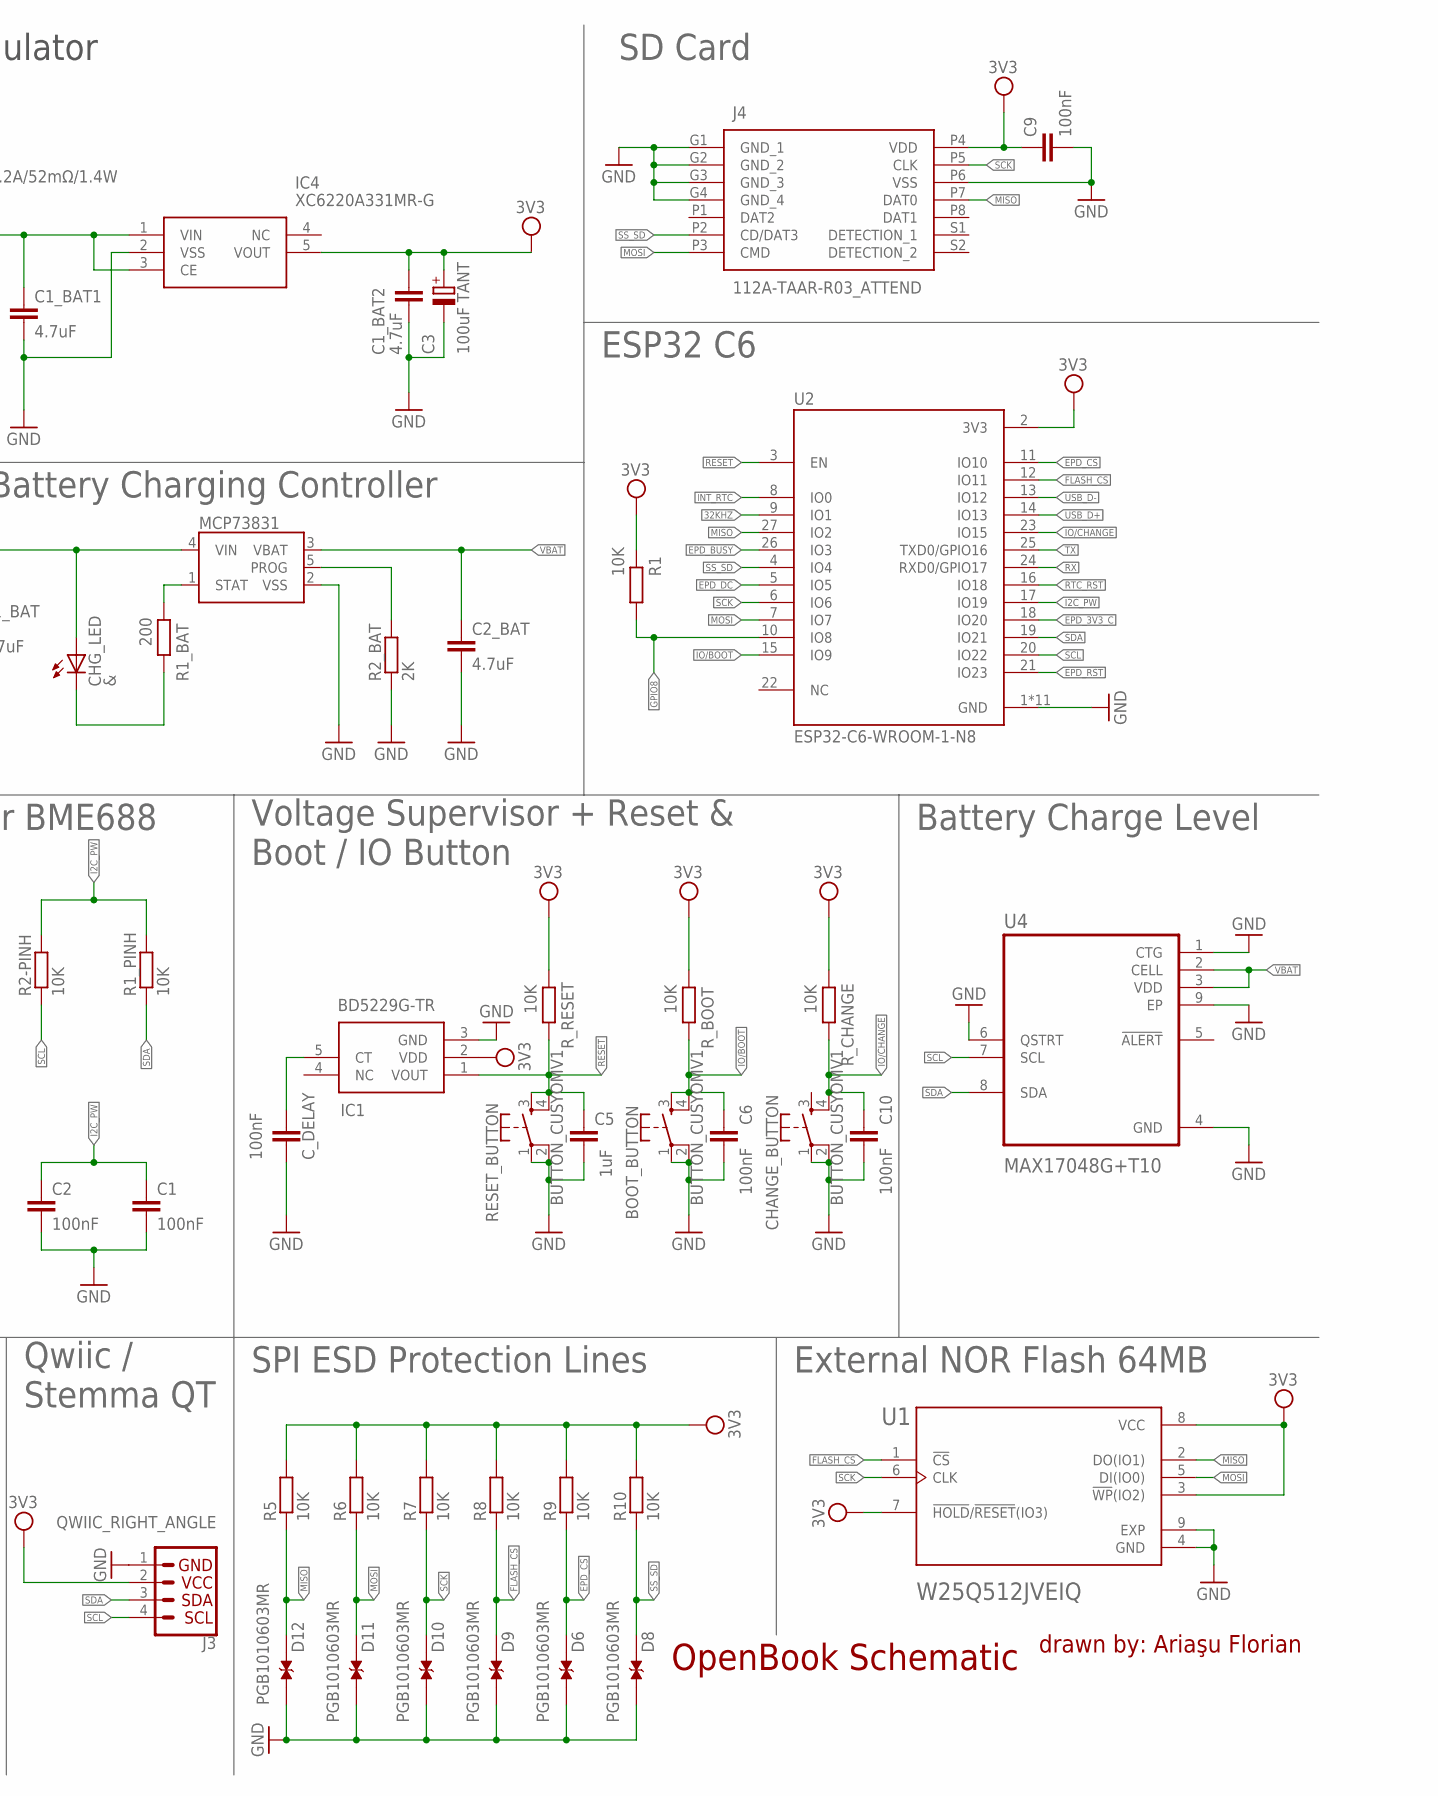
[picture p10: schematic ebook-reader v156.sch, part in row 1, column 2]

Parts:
BOOT_BUTTON: BUTTON_CUSYOMV1; MYBUTTON
C1, C2, C4_USB, C6, C8, C9, C10: 100nF; EAGLE-LTSPICE_C0402
C1_BAT, C1_BAT1, C1_BAT2, C2_BAT, C5_USB: 4.7uF; EAGLE-LTSPICE_C0402
C3: 100uF TANT; RCL_CT3528
C4: 4.7uF/25V; EAGLE-LTSPICE_C0402
C5: 1uF; EAGLE-LTSPICE_C0402
C7: 10uF; EAGLE-LTSPICE_C0402
C10_SUPERCAP: CPH3225A; CAPCP3225X100N
CHANGE_BUTTON: BUTTON_CUSYOMV1; MYBUTTON
CHG_LED: &; ADAFRUIT_CHIP-LED0603
C_DELAY: 100nF; EAGLE-LTSPICE_C0402
D1: USBLC6-2SC6Y; SOT95P280X145-6N
D2, D7: ESP32_WROVER_AVX---SD0805S020S1R0_AVX_SD0805S020S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; ESP32_WROVER_AVX---SD0805S020S1R0_AVX_SD0805S020S1R0_0
D3, D4, D5: MBR0530; SOD3716X135N
D6, D8, D9, D10, D11, D12: PGB1010603MR; DIOC1608X36N
EPD_C1, EPD_C2, EPD_C6, EPD_C7, EPD_C8, EPD_C9, EPD_C10, EPD_C11, EPD_C12: 1uF/50V; EAGLE-LTSPICE_C0402
EPD_C5: 0.1uF/50V; EAGLE-LTSPICE_C0402
IC1: BD5229G-TR; SOT95P280X125-5N
IC4: XC6220A331MR-G; SOT95P280X120-5N
J1: FH34SRJ-24S-0.5SH_99_; FH34SRJ24S05SH99
J2: SAMACSYS_PARTS_USB4110-GF-A; SAMACSYS_PARTS_USB4110GFA
J3: QWIIC_RIGHT_ANGLE; JST04_1MM_RA
J4: 112A-TAAR-R03_ATTEND; 112ATAARR03ATTEND
L1: 68uH; IND_4828-WE-TPC_WRE
MCP73831: ESP32_WROVER_SPARKFUN-IC-POWER_MCP73831; ESP32_WROVER_SPARKFUN-IC-POWER_SOT23-5
PFMF.050.1: ESP32C6_VARISTORCN1812; ESP32C6_VARISTOR_CT/CN1812
Q1, Q2: 20V/4.2A/52mΩ/1.4W; ESP32_WROVER_SPARKFUN-DISCRETESEMI_SOT23-3
Q3: SI1308EDL-T1-GE3; SOT65P210X110-3N
R1, R1_PINH, R1_PINH1, R2-PINH, R2-PINH1, R4, R5, R6, R7, R8, R9, R10: 10K; ESP32_WROVER_EAGLE-LTSPICE_R0402
R1_BAT: 200; ESP32_WROVER_EAGLE-LTSPICE_R0402
R1_PWRUSB: 100K; ESP32_WROVER_EAGLE-LTSPICE_R0402
R2: 2.2; ESP32_WROVER_EAGLE-LTSPICE_R0402
R2-USB: 5K1; ESP32_WROVER_EAGLE-LTSPICE_R0402
R2-USB1: 5k1; ESP32_WROVER_EAGLE-LTSPICE_R0402
R2_BAT: 2K; ESP32_WROVER_EAGLE-LTSPICE_R0402
R3: 0.47; ESP32_WROVER_EAGLE-LTSPICE_R0402
RESET_BUTTON: BUTTON_CUSYOMV1; MYBUTTON
R_BOOT: 10K; ESP32_WROVER_EAGLE-LTSPICE_R0402
R_CAPACITOR: 15; ESP32_WROVER_EAGLE-LTSPICE_R0402
R_CHANGE: 10K; ESP32_WROVER_EAGLE-LTSPICE_R0402
R_CL1: 10K; ESP32_WROVER_EAGLE-LTSPICE_R0402
R_RESET: 10K; ESP32_WROVER_EAGLE-LTSPICE_R0402
SENSOR2: ESP32_WROVER_BME680_BME680; ESP32_WROVER_BME680_PSON80P300X300X100-8N
SJ1: T; SJ
TP1, TP2, TP3, TP4, TP5, TP6, TP7, TP8, TP9, TP10, TP11, TP12, TP13, TP14, TP15, TP16, TP17: TPTP20R; TP20R
U1: W25Q512JVEIQ; SON127P600X800X80-9N
U2: ESP32-C6-WROOM-1-N8; XCVR_ESP32-C6-WROOM-1-N8
U3: DS3231SN#; SOIC127P1032X265-16N
U4: MAX17048G+T10; SON50P200X200X80-9N

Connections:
3V3: C1_BAT2.1, C3.+, C9.1, D7.2 (ANODE), IC1.2 (VDD), IC4.5 (VOUT), J3.2, J4.P4 (VDD), Q2.3 (D), R1.2, R1_PINH1.2, R2-PINH1.2, R5.2, R6.2, R7.2, R8.2, R9.2, R10.2, R_BOOT.2, R_CHANGE.2, R_CL1.2, R_RESET.2, TP16.TP, U1.3 (!WP!(IO2)), U1.7 (!HOLD!/!RESET!(IO3)), U1.8 (VCC), U2.2 (3V3), U3.2 (VCC)
32KHZ: R2-PINH1.1, U2.9 (IO1), U3.1 (32KHZ)
DN: D1.1 (I/O1_1), J2.A7, J2.B7
DP: D1.3 (I/O2_1), J2.A6, J2.B6
EPD_3V3: C7.1, EPD_C5.2, J1.15, J1.16, L1.2, Q2.2 (S), TP17.TP
EPD_3V3_C: Q2.1 (G), R_CL1.1, TP13.TP, U2.18 (IO20)
EPD_BUSY: J1.9, TP9.TP, U2.26 (IO3)
EPD_CS: D11.2, J1.12, R9.1, TP10.TP, U2.11 (IO10)
EPD_DC: J1.11, TP11.TP, U2.5 (IO5)
EPD_RST: J1.10, TP12.TP, U2.21 (IO23)
FLASH_CS: D10.2, R8.1, U1.1 (!CS), U2.12 (IO11)
GDR: J1.2, Q3.1 (G), R4.2
GND: BOOT_BUTTON.1, BOOT_BUTTON.2, C1.2, C1_BAT.2, C1_BAT1.2, C1_BAT2.2, C2.2, C2_BAT.2, C3.-, C4_USB.2, C5.2, C5_USB.2, C6.2, C7.2, C8.2, C9.2, C10.2, C10_SUPERCAP.1, CHANGE_BUTTON.1, CHANGE_BUTTON.2, C_DELAY.2, D1.5 (VBUS), D3.1 (K), D6.1, D8.1, D9.1, D10.1, D11.1, D12.1, EPD_C1.1, EPD_C2.1, EPD_C5.1, EPD_C6.1, EPD_C7.1, EPD_C8.1, EPD_C9.2, EPD_C10.1, EPD_C11.1, EPD_C12.1, IC1.3 (GND), IC4.2 (VSS), J1.8, J1.17, J1.MP1, J1.MP2, J2.A1, J2.A12, J2.B1, J2.B12, J2.MP1, J2.MP2, J2.MP3, J2.MP4, J3.1, J4.G1 (GND_1), J4.G2 (GND_2), J4.G3 (GND_3), J4.G4 (GND_4), J4.P6 (VSS), MCP73831.2 (VSS), R1_PWRUSB.1, R2.1, R2-USB.2, R2-USB1.1, R2_BAT.1, R4.1, RESET_BUTTON.1, RESET_BUTTON.2, SENSOR2.1 (GND), SENSOR2.5 (SDO), SENSOR2.7 (GND), SJ1.1, TP4.TP, TP5.TP, U1.4 (GND), U1.9 (EXP), U2.1 (GND), U2.28 (GND), U2.29_1 (GND), U2.29_2 (GND), U2.29_3 (GND), U2.29_4 (GND), U2.29_5 (GND), U2.29_6 (GND), U2.29_7 (GND), U2.29_8 (GND), U2.29_9 (GND), U3.13 (GND), U4.1 (CTG), U4.4 (GND), U4.6 (QSTRT), U4.9 (EP)
GPIO8: R1.1, U2.10 (IO8)
I2C_PW: C1.1, C2.1, R1_PINH.2, R2-PINH.2, SENSOR2.2 (CSB), SENSOR2.6 (VDDIO), SENSOR2.8 (VDD), U2.17 (IO19)
INT_RTC: R1_PINH1.1, TP15.TP, U2.8 (IO0), U3.3 (SQW/!INT)
IO/BOOT: BOOT_BUTTON.3, BOOT_BUTTON.4, C6.1, R_BOOT.1, U2.15 (IO9)
IO/CHANGE: C10.1, CHANGE_BUTTON.4, R_CHANGE.1, U2.23 (IO15)
MISO: D6.2, J4.P7 (DAT0), R5.1, TP6.TP, U1.2 (DO(IO1)), U2.27 (IO2)
MOSI: D9.2, J1.14, J4.P3 (CMD), R6.1, TP7.TP, U1.5 (DI(IO0)), U2.7 (IO7)
unnamed: J2.A5, R2-USB1.2
unnamed: J2.B5, R2-USB.1
unnamed: EPD_C11.2, J1.23
unnamed: C1_BAT1.1, D2.1 (CATHODE), IC4.1 (VIN), IC4.3 (CE), Q1.2 (S)
unnamed: CHG_LED.C, R1_BAT.1
unnamed: C4.1, D3.2 (A), D4.1 (K)
unnamed: MCP73831.1 (STAT), R1_BAT.2
unnamed: MCP73831.5 (PROG), R2_BAT.2
unnamed: EPD_C1.2, J1.4
unnamed: EPD_C2.2, J1.5
unnamed: C_DELAY.1, IC1.5 (CT)
unnamed: D7.1 (CATHODE), R_CAPACITOR.1
unnamed: EPD_C12.2, J1.24
unnamed: EPD_C10.2, J1.22
unnamed: EPD_C9.1, J1.21
unnamed: EPD_C8.2, J1.20
unnamed: EPD_C7.2, J1.19
unnamed: EPD_C6.2, J1.18
PREVGH: D5.1 (K)
PREVGL: D4.2 (A)
RESE: J1.3, Q3.2 (S), R3.2
RESE': R2.2, R3.1, SJ1.2
RESET: C5.1, IC1.1 (VOUT), RESET_BUTTON.3, RESET_BUTTON.4, R_RESET.1, U2.3 (EN)
RTC_RST: U2.16 (IO18), U3.4 (!RST)
RX: TP2.TP, U2.24 (RXD0/GPIO17)
SCK: D8.2, J1.13, J4.P5 (CLK), R7.1, TP8.TP, U1.6 (CLK), U2.6 (IO6)
SCL: J3.4, R2-PINH.1, SENSOR2.4 (SCK), U2.20 (IO22), U3.16 (SCL), U4.7 (SCL)
SDA: J3.3, R1_PINH.1, SENSOR2.3 (SDI), U2.19 (IO21), U3.15 (SDA), U4.8 (SDA)
SRC: C4.2, D5.2 (A), L1.1, Q3.3 (D)
SS_SD: D12.2, J4.P2 (CD/DAT3), R10.1, U2.4 (IO4)
TX: TP1.TP, U2.25 (TXD0/GPIO16)
USB_D+: D1.4 (I/O2_2), U2.14 (IO13)
USB_D-: D1.6 (I/O1_2), U2.13 (IO12)
VBAT: C2_BAT.1, D2.2 (ANODE), MCP73831.3 (VBAT), Q1.1 (G), R1_PWRUSB.2, TP3.TP, U4.2 (CELL), U4.3 (VDD)
VBUS: C1_BAT.1, C4_USB.1, C5_USB.1, CHG_LED.A, D1.2 (GND), MCP73831.4 (VIN), PFMF.050.1.2, TP14.TP
VRTC: C8.1, C10_SUPERCAP.2, R_CAPACITOR.2, U3.14 (VBAT)
VUSB: J2.A4, J2.A9, J2.B4, J2.B9, PFMF.050.1.1

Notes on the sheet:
USB C connector & ESD protection
LDO Voltage Regulator
SD Card
Display Type Selector
E-Paper Drive Circuit
Li-Po Battery Charging Controller
ESP32 C6
E-Paper Display Header
EPD Power
Environmental Sensor BME688
Voltage Supervisor + Reset & Boot / IO Button
Battery Charge Level
RTC Module DS3231SN
Test Pads
Qwiic / Stemma QT
SPI ESD Protection Lines
External NOR Flash 64MB
OpenBook Schematic
drawn by: Ariaşu Florian

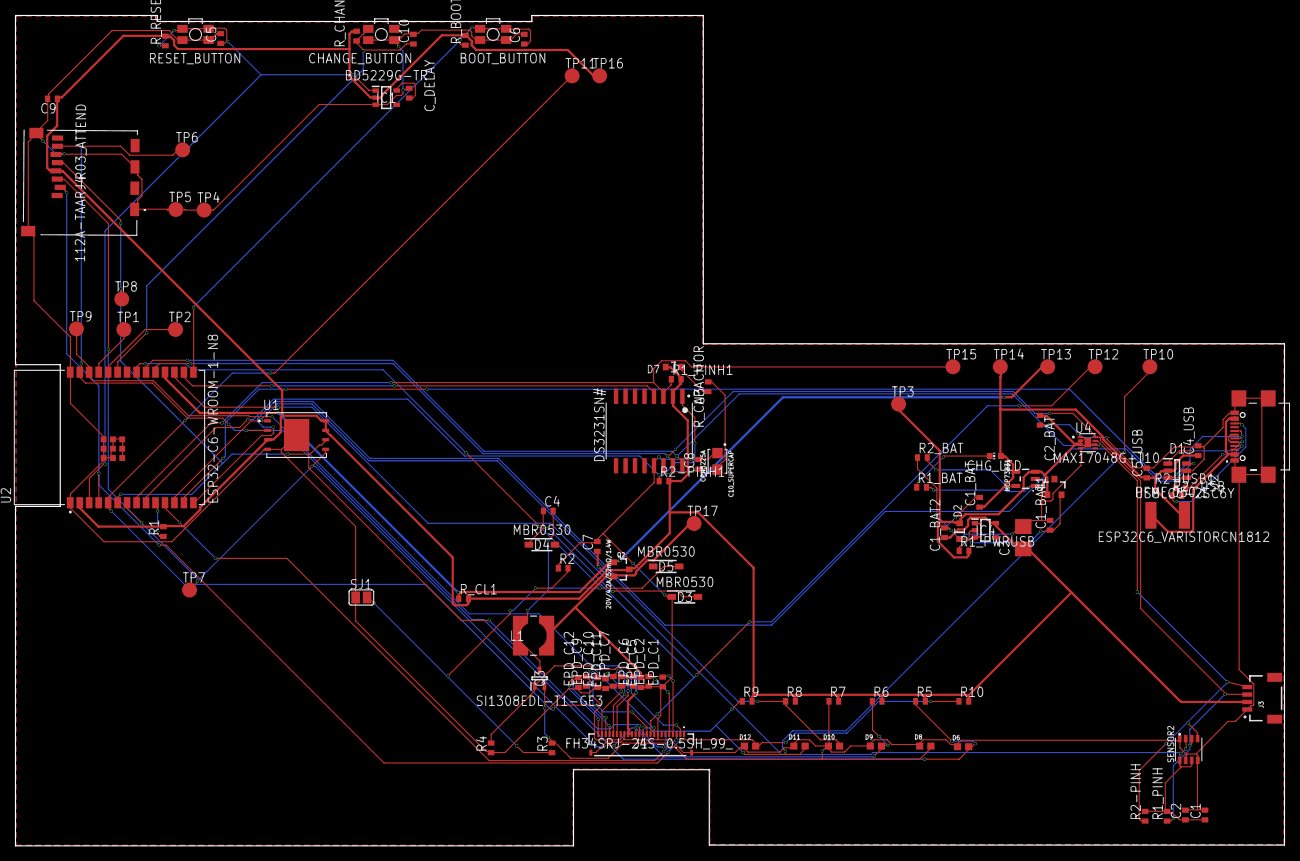
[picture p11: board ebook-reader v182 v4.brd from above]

Board: 2 copper layers, 170.1 x 111.3 mm, 103 parts (0 on the bottom side), 55 nets.

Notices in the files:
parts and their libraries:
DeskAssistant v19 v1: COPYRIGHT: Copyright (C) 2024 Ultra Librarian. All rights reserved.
